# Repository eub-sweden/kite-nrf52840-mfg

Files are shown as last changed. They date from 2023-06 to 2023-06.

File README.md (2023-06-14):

# Kite-nRF52840

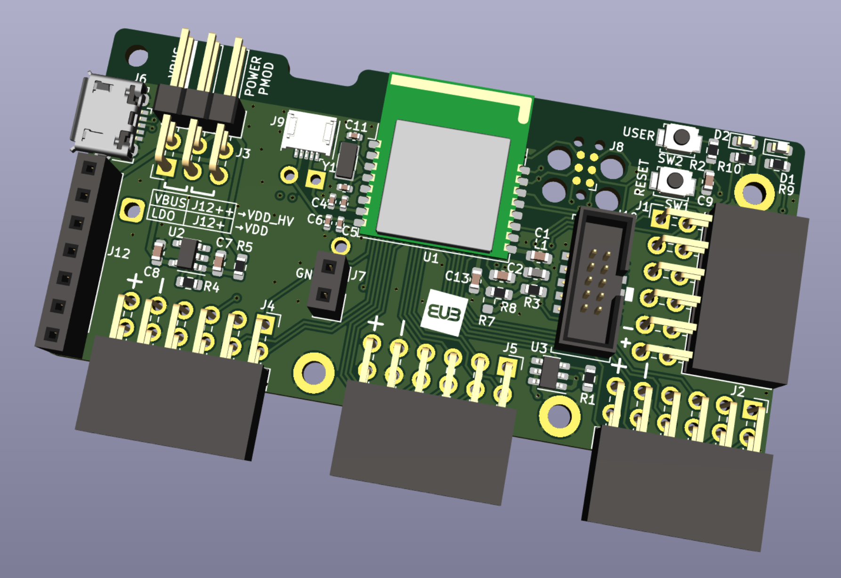
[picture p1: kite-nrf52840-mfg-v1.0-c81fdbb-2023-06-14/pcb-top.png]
top
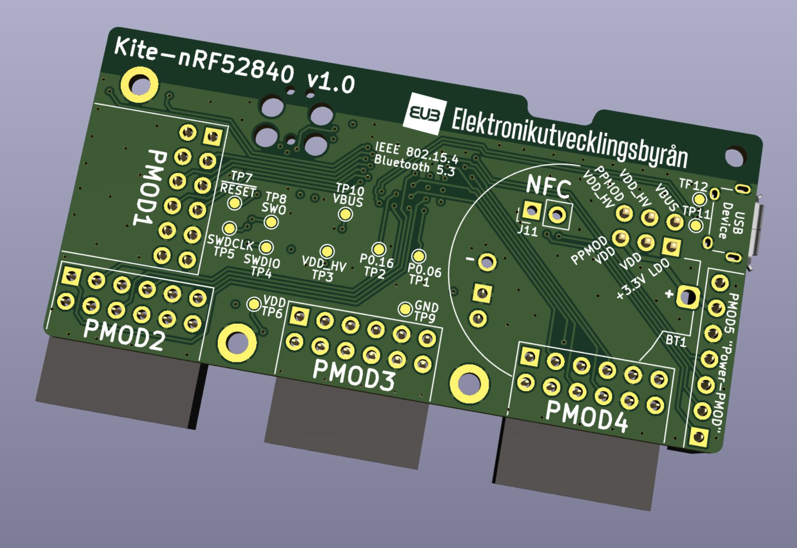
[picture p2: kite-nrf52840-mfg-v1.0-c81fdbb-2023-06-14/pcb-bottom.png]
bot


## Functionality
- Bluetooth 5.3 SoC (Nordic nRF52840)
- Four 12-pin female connectors
  - Digilent Pmod™ Compatible
  - One port with controllable VDD supply voltage
- +3.3V LDO regulator
- USB Micro B connector for data and/or power
- Two NFC antenna connectors
  - Nordic flex PCB antenna port
  - 2-pin, 2.54mm pitch, plated through holes
- Configurable power supply source
  - USB Micro B +5V
  - VDD_HV pin header (2.5V to 5.5V)
  - VDD pin header (1.7V to 3.6V)
  - CR2032 coin cell battery
- Two SWD debug connectors
  - 6-pin Tag-Connect (TC2030)
  - 10-pin Cortex Debug
- Two LEDs (green, amber)
- Two buttons (reset, user)

## Board releases
- [[v1.0] - 2023-04-27](kite-nrf52840-mfg-v1.0-c81fdbb-2023-06-14)

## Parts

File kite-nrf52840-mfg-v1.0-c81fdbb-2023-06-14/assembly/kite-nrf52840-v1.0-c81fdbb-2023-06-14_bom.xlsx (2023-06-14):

References | Component | Value | Rating | Package | Manufacturer | Manufacturer part number | Supplier | Supplier part number | Quantity Per PCB | Or equivalent
C11 C12 | Capacitor, Ceramic | 12p |  | 0402 | Samsung | CL05C120JB5NNNC | Digi-Key | 1276-1178-1-ND | 2 | y
C7 C8 C9 | Capacitor, Ceramic | 100n |  | 0603 | Samsung | CL10B104KB8NNNC | Digi-Key | 1276-1000-1-ND | 3 | y
C1 | Capacitor, Ceramic | 1u |  | 0603 | Samsung | CL10A105KP8NNNC | Digi-Key | 1276-1182-1-ND | 1 | y
C2 C13 | Capacitor, Ceramic | 4.7u |  | 0603 | Samsung | CL10A475KP8NNNC | Digi-Key | 1276-1044-1-ND | 2 | y
D1 | LED, Green | GREEN |  | 0603 | Lite-On | LTST-C191KGKT | Digi-Key | 160-1446-1-ND | 1 | y
D2 | LED, Orange | ORANGE |  | 0603 | Lite-On | LTST-C191KFKT | Digi-Key | 160-1445-1-ND | 1 | y
J10 | Connector, Pin header, 2x5, 1.27mm pitch | Cortex-Debug |  |  | CNC Tech | 3220-10-0300-00 | Digi-Key | 1175-1629-ND | 1
J9 | Connector, FPC, 5POS, 0.5mm pitch | NFC_FPC |  |  | Molex | 512810598 | Digi-Key | 900-0512810598CT-ND | 1
J1 | Connector, Female socket, Right angle, 2x6, 2.54mm pitch | PMOD1 |  |  | Sullins Connector Solutions | PPPC062LJBN-RC | Digi-Key | S5559-ND | 1
J12 | Connector, Female socket, 1x7, 2.54mm pitch | PMOD5 |  |  | Samtec | SSA-107-S-T | Digi-Key | SAM1122-07-ND | 1
J7 | Connector, Female socket, 1x2, 2.54mm pitch | PPMOD support |  |  | Samtec | SSA-102-S-T | Digi-Key | SAM1122-02-ND | 1
J3 | Connector, Male pin, Right angle, 2x3, 2.54mm pitch | PSU config |  |  | Amphenol | 10129382-906002BLF | Digi-Key | 10129382-906002BLF-ND | 1
J6 | Connector, USB, Micro B | USB Micro-B |  |  | Amphenol | 10118194-0001LF | Digi-Key | 609-4618-1-ND | 1
L1 | Inductor, SMD | 10u | >80mA | 0603 | Taiyo Yuden | LBMF1608T100K | Digi-Key | 587-1714-1-ND | 1 | y
R3 R4 R5 R8 | Resistor, Chip | 0 |  | 0603 | Yageo | RC0603JR-070RL | Digi-Key | 311-0.0GRCT-ND | 4 | y
R2 R9 R10 | Resistor, Chip | 1k |  | 0603 | Yageo | RC0603FR-071KL | Digi-Key | 311-1.00KHRCT-ND | 3 | y
R1 | Resistor, Chip | 100k |  | 0603 | Yageo | RC0603FR-07100KL | Digi-Key | 311-100KHRCT-ND | 1 | y
SW1 SW2 | Switch, Tactile, SPST, Momentary | ~ |  |  | Omron | B3U-1000P | Digi-Key | SW1020CT-ND | 2
U2 | PMIC, Regulator, LDO | AP7354-33W5-7 |  | SOT-23-5 | Diodes Inc. | AP7354-33W5-7 | Digi-Key | AP7354-33W5-7DICT-ND | 1 | y
U1 | Module, MCU + Bluetooth SoC | BT840 |  |  | Fanstel | BT840 | Digi-Key | 1914-1018-1-ND | 1
U3 | PMIC, High-side switch | SiP32510DT |  | SOT-23-6 | Vishay | SIP32510DT-T1-GE3 | Digi-Key | SIP32510DT-T1-GE3CT-ND | 1 | y
Y1 | Crystal, Cl=9pF, 32.768kHz | Crystal | ±20ppm | 3.2x1.5mm | EPSON | FC-135 32.7680KA-AC0 | Digi-Key | SER4084CT-ND | 1

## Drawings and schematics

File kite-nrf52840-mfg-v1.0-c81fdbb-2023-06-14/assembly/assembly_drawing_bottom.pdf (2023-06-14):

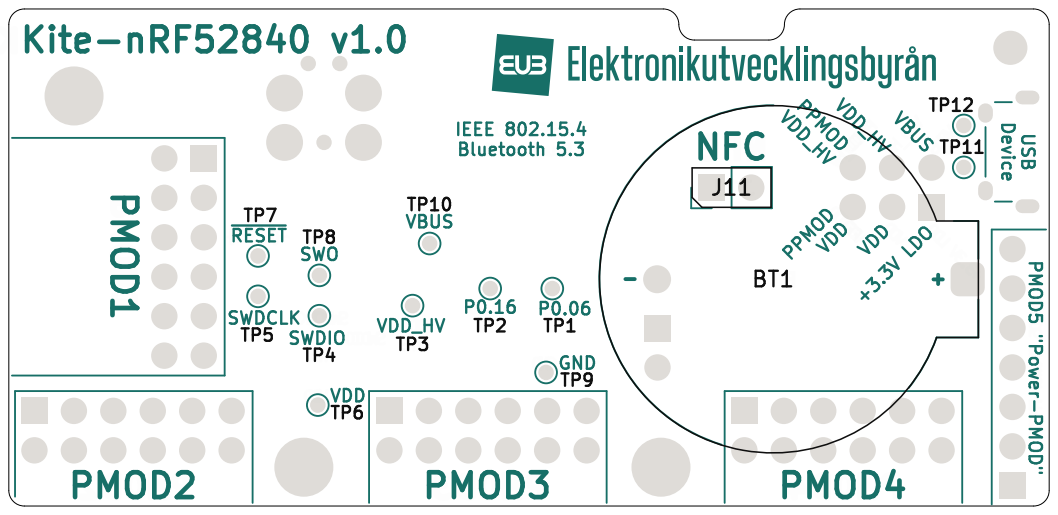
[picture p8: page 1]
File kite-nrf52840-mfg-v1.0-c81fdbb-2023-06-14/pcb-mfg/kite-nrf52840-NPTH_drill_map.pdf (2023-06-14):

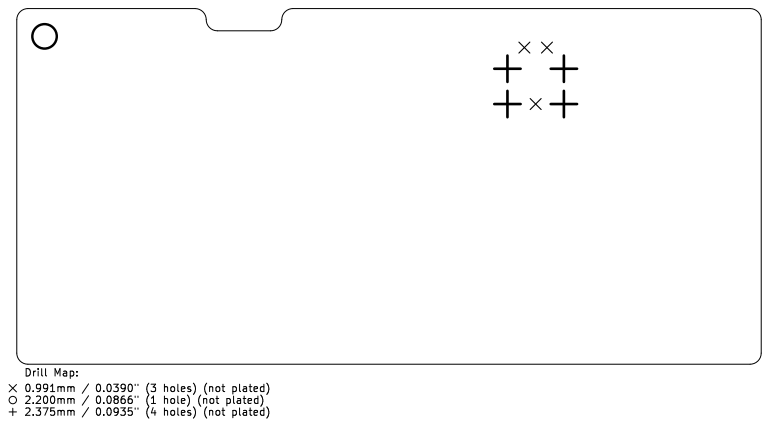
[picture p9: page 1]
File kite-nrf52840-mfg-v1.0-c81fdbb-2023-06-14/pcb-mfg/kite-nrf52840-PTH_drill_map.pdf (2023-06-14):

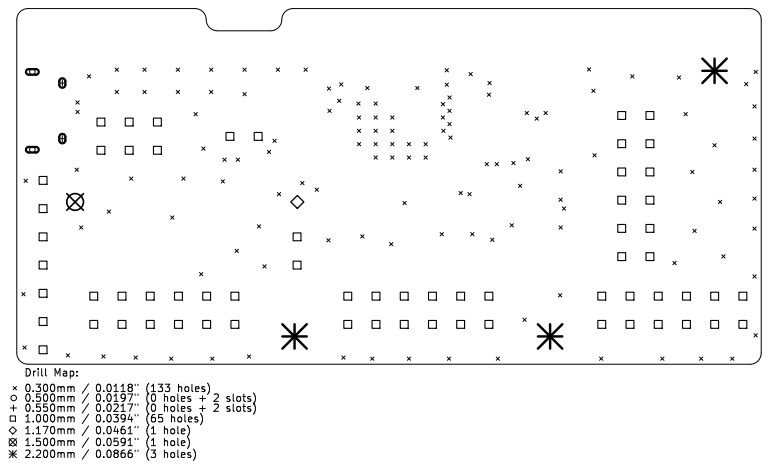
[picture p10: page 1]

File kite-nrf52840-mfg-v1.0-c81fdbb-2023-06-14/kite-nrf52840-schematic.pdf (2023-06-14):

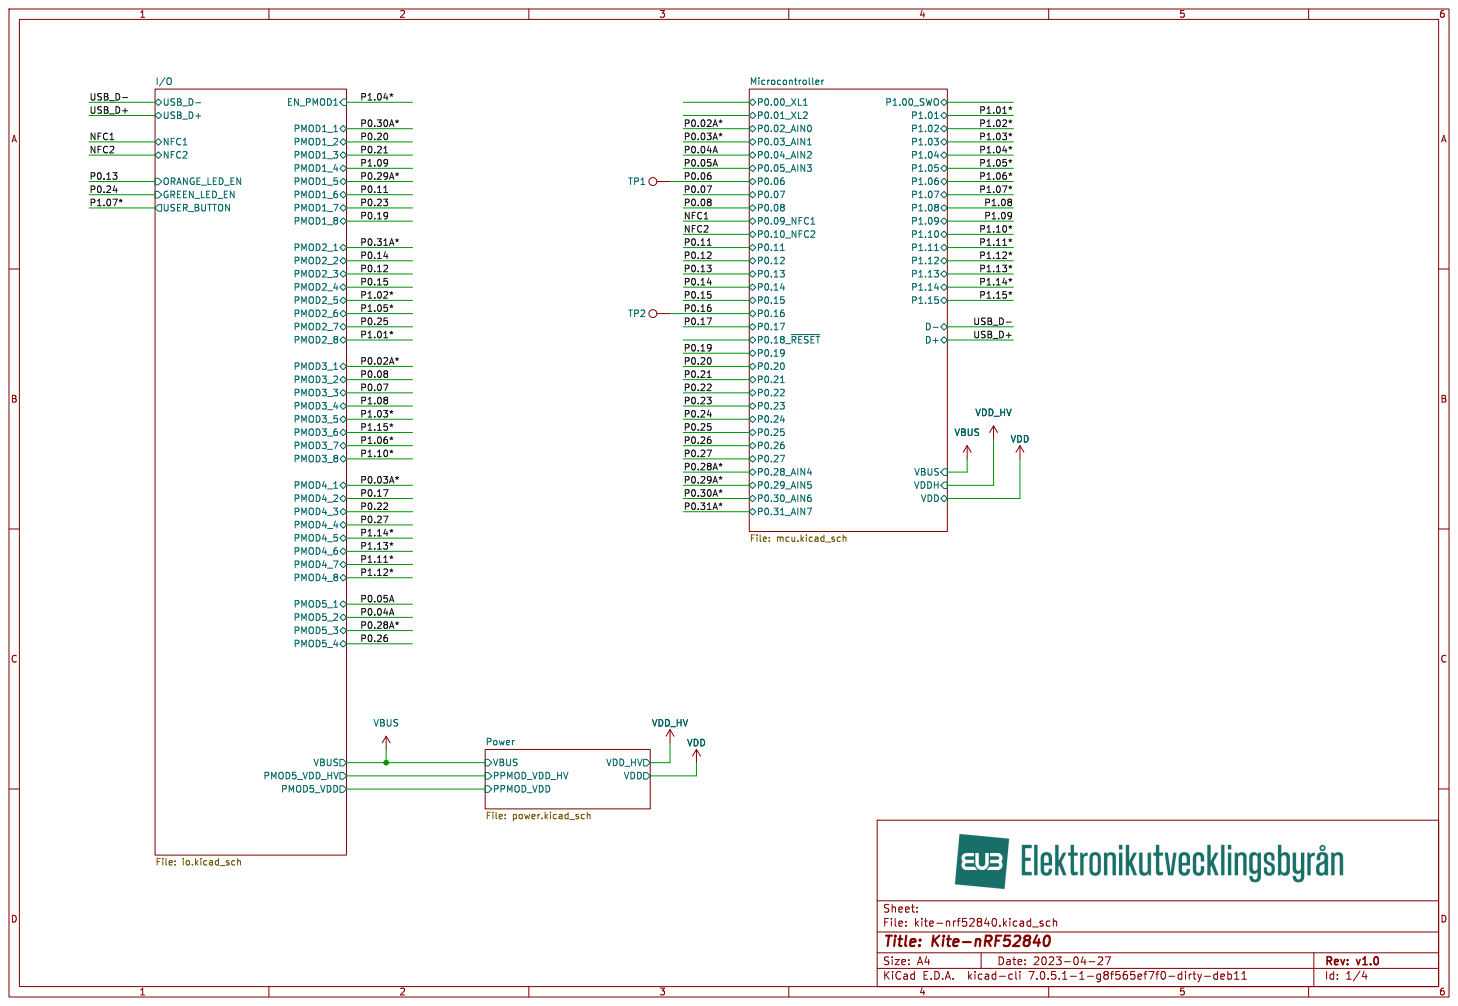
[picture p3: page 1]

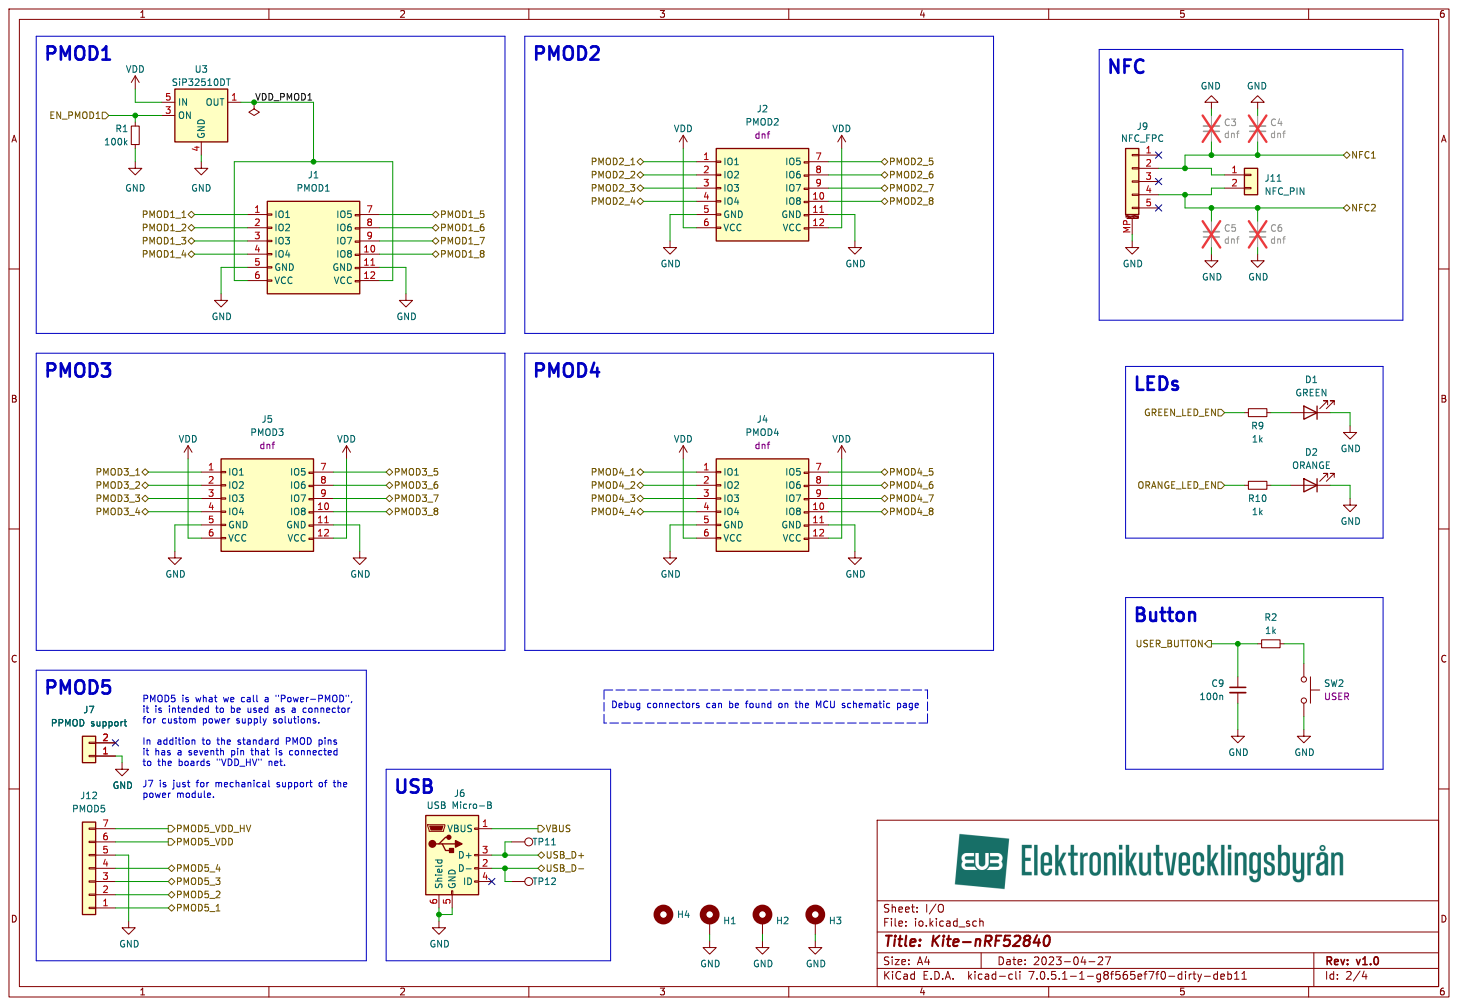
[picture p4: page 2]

it is intended to be used as a connector
for custom power supply solutions.

it has a seventh pin that is connected

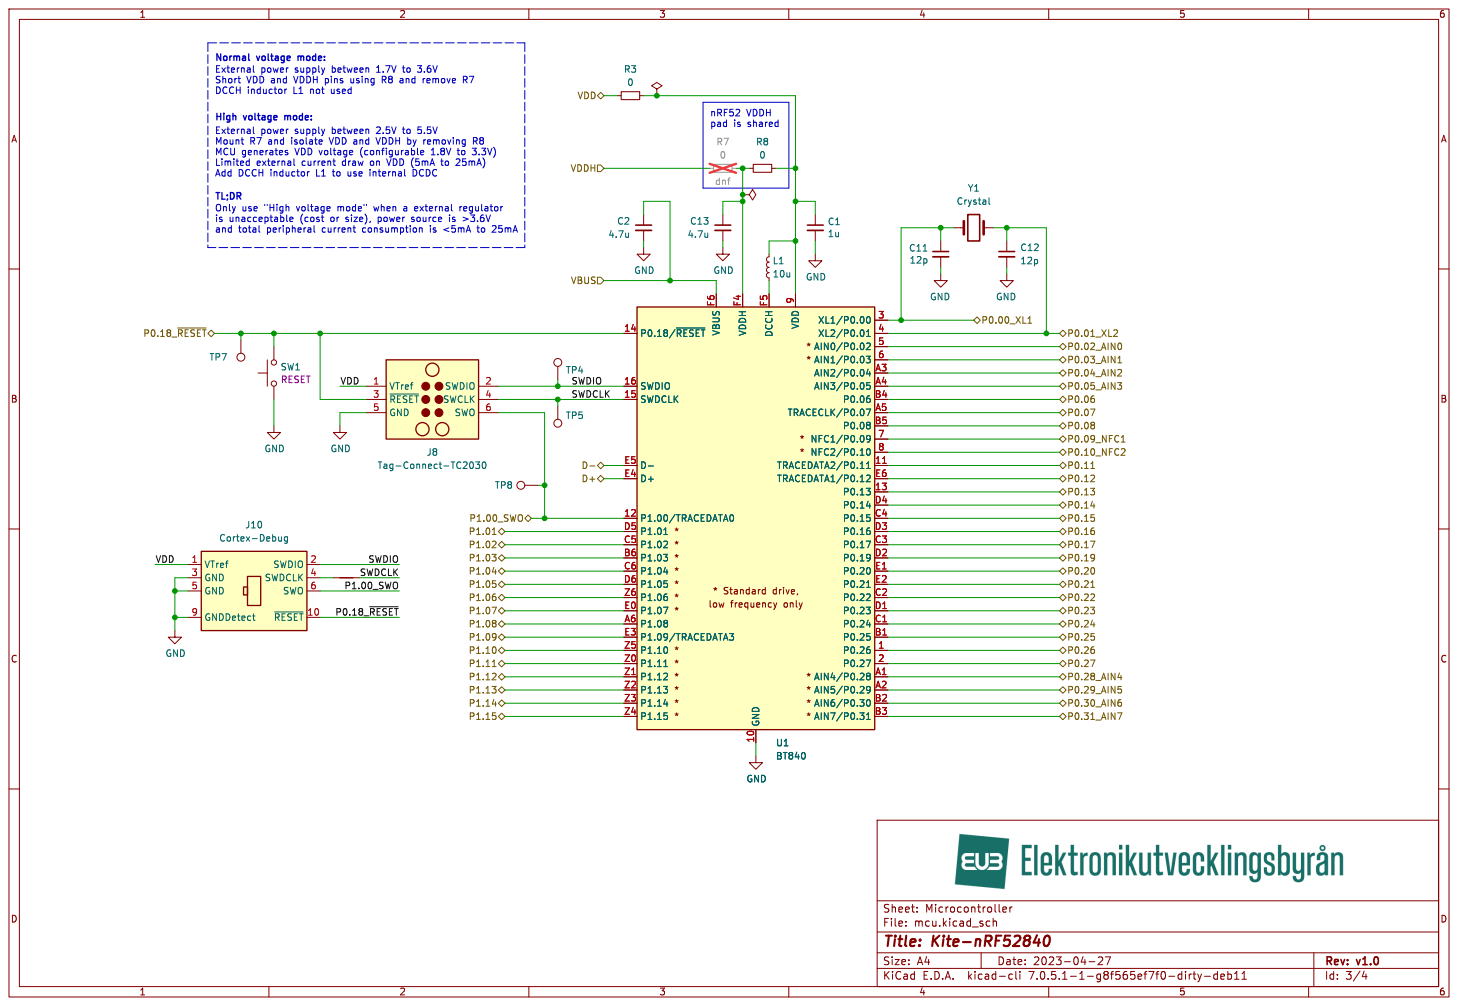
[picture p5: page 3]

High voltage mode: External power supply between 1.7V to 3.6V

9 AIN4/P0.28 A1 AIN5/P0.29 A2 AIN2/P0.04 A3 AIN3/P0.05 A4 TRACECLK/P0.07 A5 P1.08 A6 P0.25 B1 AIN6/P0.30 B2 AIN7/P0.31 B3 P0.06 B4 P0.08 B5 P1.03 B6 P0.24 C1 P0.22 C2 P0.17 C3 P0.15 C4 P1.02 C5 P1.04 C6 P0.23 D1 P0.19 D2 P0.16 D3 P0.14 D4 P1.01 D5 P1.05 D6 P1.07 E0 P0.20 E1 P0.21 E2 P1.09/TRACEDATA3 E3 D+ E4 D- E5 TRACEDATA1/P0.12 E6 VDDH F4 DCCH F5 VBUS F6 P1.11 Z0 P1.12 Z1 P1.13 Z2 P1.14 Z3 P1.15 Z4 P1.10 Z5 P1.06 Z6 U1BT840

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

File: mcu.kicad_sch Sheet: Microcontroller
Id: 3/4 Title: Kite-nRF52840

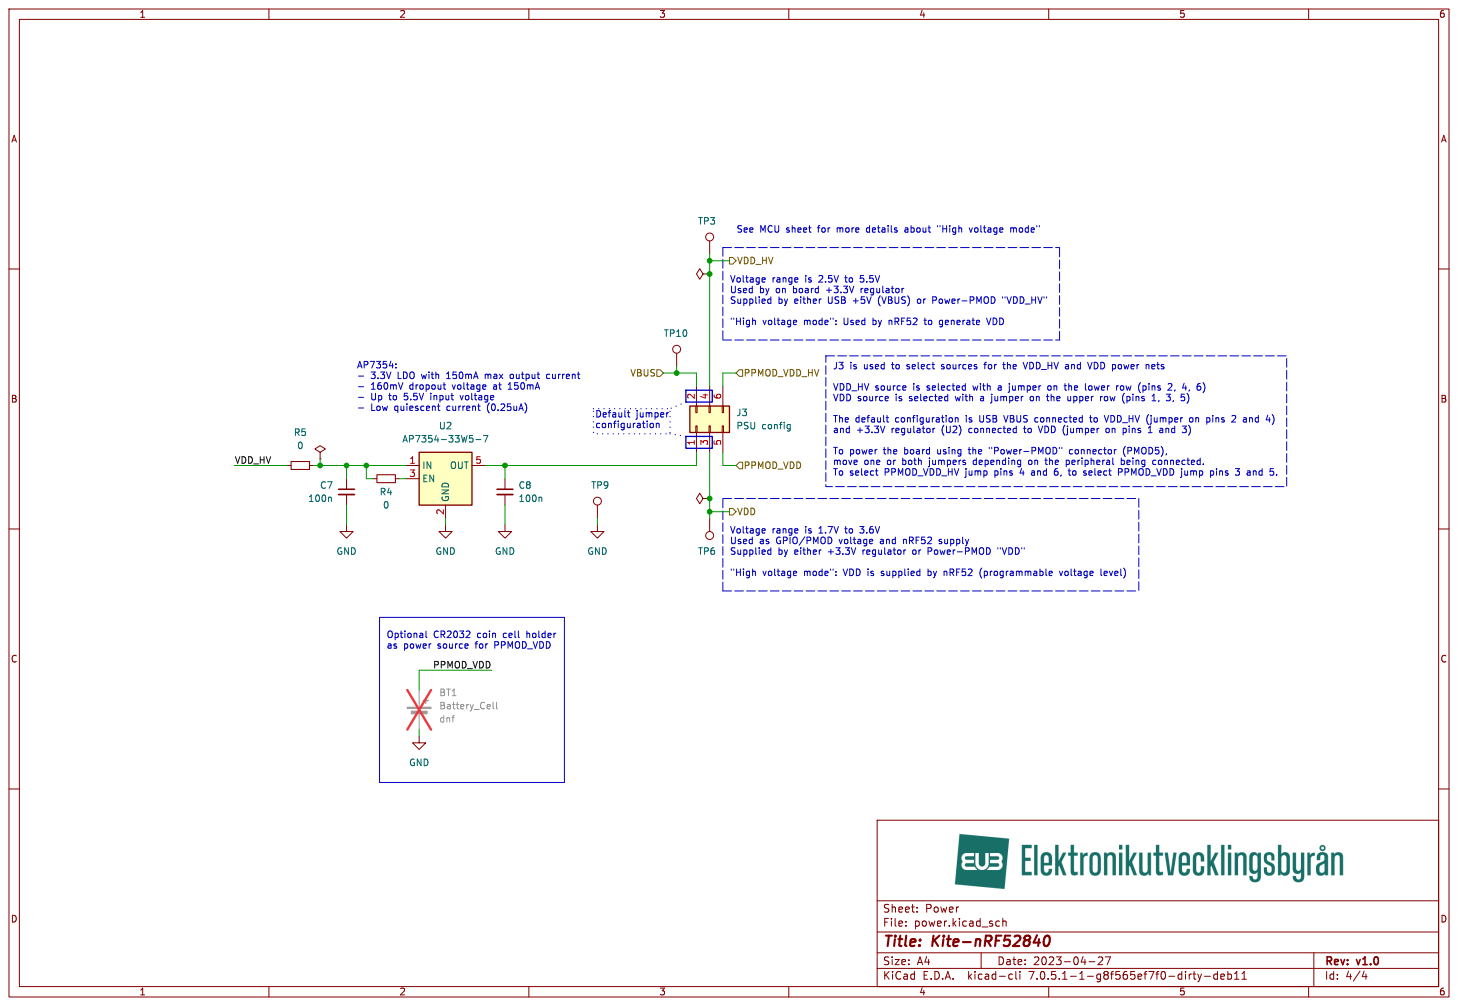
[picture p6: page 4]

See MCU sheet for more details about "High voltage mode" Voltage range is 1.7V to 3.6V Used as GPIO/PMOD voltage and nRF52 supply
J3PSU config VDD_HV
Voltage range is 2.5V to 5.5V Used by on board +3.3V regulator

"High voltage mode": Used by nRF52 to generate VDD

- Up to 5.5V input voltage

Optional CR2032 coin cell holder as power source for PPMOD_VDD

File: power.kicad_sch Sheet: Power GND

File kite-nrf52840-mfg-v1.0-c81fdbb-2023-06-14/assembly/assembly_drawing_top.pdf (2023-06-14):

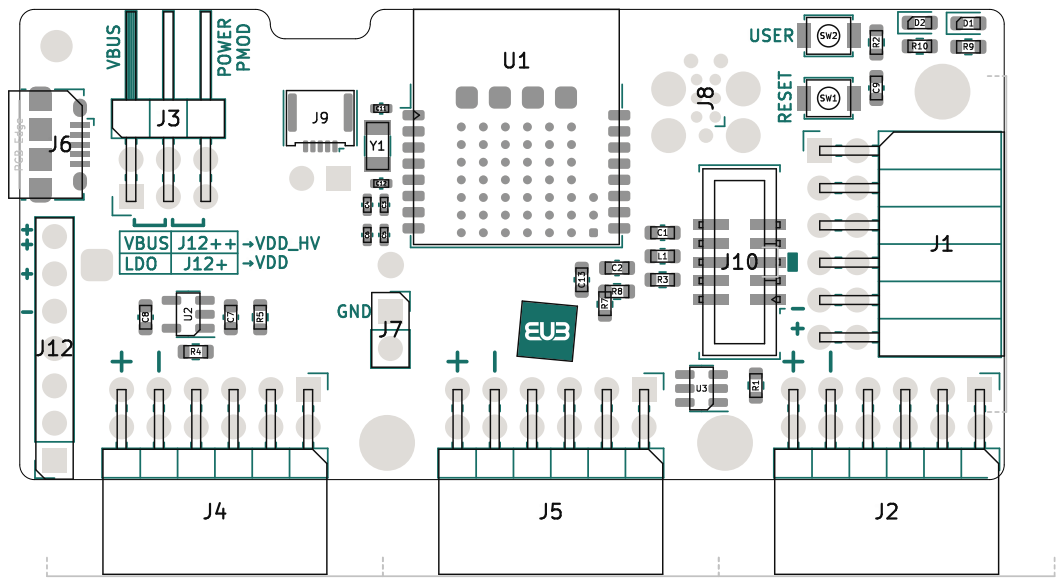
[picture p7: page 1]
RESET; VBUS; →VDD_HV; USER; →VDD; GND; LDO; POWER; PMOD
